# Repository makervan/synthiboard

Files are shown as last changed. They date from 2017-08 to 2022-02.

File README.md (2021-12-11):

# Synthiboard

An Arduino-based synthesizer, with multiple firmwares to allow for different sounds. See http://wiki.makervan.de/wiki/Synthiboard for more information.

## Firmware
There are multiple firmwares available for the Synthiboard, you can find some in this repository.
* Auduino
* R2R Drum Machine
* Glitch Storm by [Spherical Sound Society](https://github.com/spherical-sound-society/glitch-storm), adapted to work with Synthiboard pinout.

## License
Hardware designs created by Severin Schols, and shared under CC-BY-SA-4.0. See LICENSE for more information.

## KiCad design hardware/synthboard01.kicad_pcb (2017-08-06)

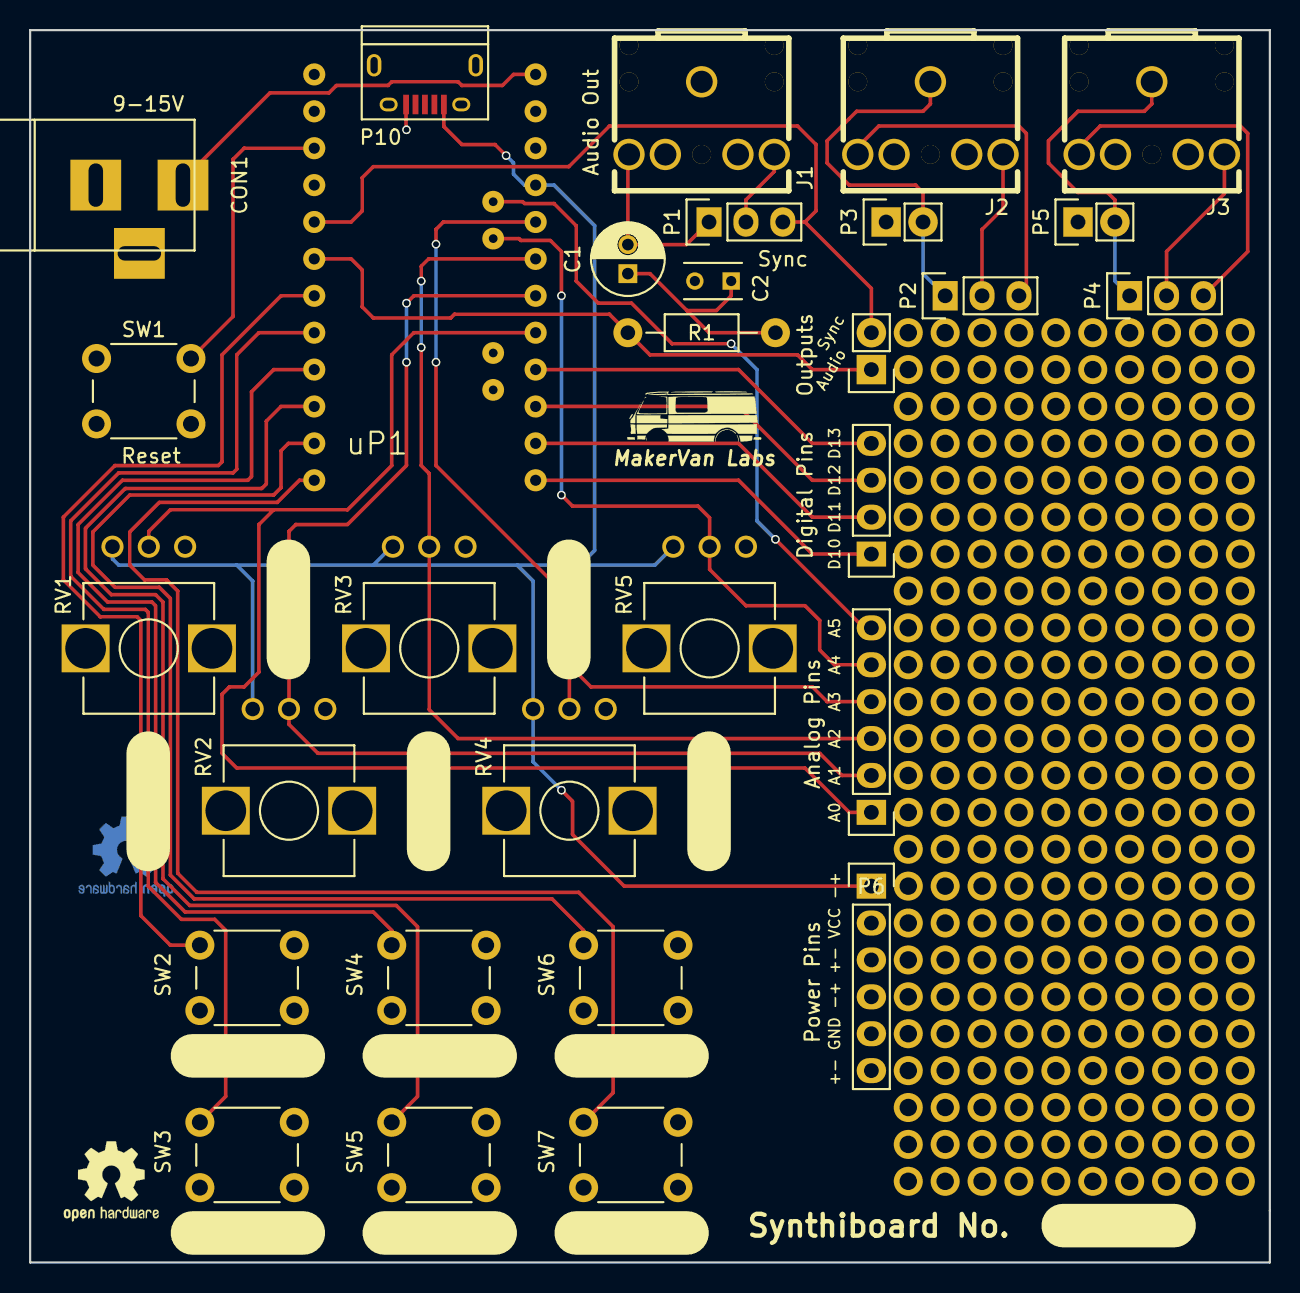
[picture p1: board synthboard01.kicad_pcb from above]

Board: 2 copper layers, 85.3 x 84.8 mm, 30 parts (0 on the bottom side), 31 nets.

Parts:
C1: 10µ; C_Radial_D5_L11_P2
C2: 10n; C_Rect_L4_W2.5_P2.5
CON1: 9-15V; BARREL_JACK
J1: Audio Out; AudioJack3.5mm
J2: Addit. Plug 1; AudioJack3.5mm
J3: Addit. Plug 2; AudioJack3.5mm
P1: Sync; Pin_Header_Straight_1x03
P2: AP1; Pin_Header_Straight_1x03
P3: AP1_GND; Pin_Header_Straight_1x02
P4: AP2; Pin_Header_Straight_1x03
P5: AP2_GND; Pin_Header_Straight_1x02
P6: Analog Pins; Pin_Header_Straight_1x06
P7: Digital Pins; Pin_Header_Straight_1x04
P8: Power Pins; Pin_Header_Straight_1x06
P9: Outputs; Pin_Header_Straight_1x02
P10: USB_OTG; USB_Micro-B
R1: 1k; Resistor_Horizontal_RM10mm
RV1, RV2, RV3, RV4, RV5: 10k; Potentiometer_Alpha-RV09
SW1: Reset; SW_PUSH_6mm
SW2: Button 1; SW_PUSH_6mm
SW3: Button 2; SW_PUSH_6mm
SW4: Button 3; SW_PUSH_6mm
SW5: Button 4; SW_PUSH_6mm
SW6: Button 5; SW_PUSH_6mm
SW7: Button 6; SW_PUSH_6mm
uP1: ARDUPROMINI-6; ArduProMini-6

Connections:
+9V: CON1.1, uP1.19
A0: P6.1, RV1.2, uP1.26
A1: P6.2, RV2.2, uP1.25
A2: P6.3, RV3.2, uP1.24
A3: P6.4, RV4.2, uP1.23
A4: P6.5, RV5.2, uP1.32
A5: P6.6, uP1.31
AudioOut: P9.1, R1.2, uP1.12
D10: P7.1, uP1.30
D11: P7.2, uP1.29
D12: P7.3, uP1.28
D13: P7.4, uP1.27
GND: C2.2, CON1.2, J1.1, P3.1, P5.1, P8.4, P8.5, P8.6, P10.5, RV1.1, RV2.1, RV3.1, RV4.1, RV5.1, SW1.2, SW2.2, SW3.2, SW4.2, SW5.2, SW6.2, SW7.2, uP1.10
unnamed: C1.1, C2.1, R1.1
unnamed: C1.2, J1.2, P1.1
unnamed: J1.3, P1.2
unnamed: J2.1, P2.1, P3.2
unnamed: J2.2, P2.3
unnamed: J2.3, P2.2
unnamed: J3.1, P4.1, P5.2
unnamed: J3.2, P4.3
unnamed: J3.3, P4.2
unnamed: SW1.1, uP1.9
unnamed: SW2.1, uP1.13
unnamed: SW3.1, uP1.14
unnamed: SW4.1, uP1.15
unnamed: SW5.1, uP1.16
unnamed: SW6.1, uP1.17
unnamed: SW7.1, uP1.18
Sync: P1.3, P9.2, uP1.11
VCC: P8.1, P8.2, P8.3, P10.1, RV1.3, RV2.3, RV3.3, RV4.3, RV5.3, uP1.22

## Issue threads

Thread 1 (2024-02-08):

Opening in KiCad 7.

poetaster, 2024-02-08:
Hi! It's not really possible to use the kicad files since a lot of libraries and schematic symbols are missing. Is there any way to update them? Not sure if you have the time, but I'd like to build one!

Thanks!

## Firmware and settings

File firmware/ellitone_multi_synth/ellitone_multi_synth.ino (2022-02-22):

//  ELLITONE MULTI-SYNTH is powered using the Mozzi Sonification Library for Arduino.

// I have spent the last 2.5 years exploring this library, finding the atmega328s strong and weak points when processing realtime audio

// In the following program, I attempted to squeeze as much Mozzi functionality into a single device, paired with a simple "patch and play" interface.

// Currently, this program uses 99.99% of the atmega328 program storage space. This includes the 6 WaveTable files that represent the WaveForm Shapes  <tables/AKWF_.....h>

//You might be asking "can I use my own waveforms?". Creating custom waveforms for use in mozzi is not a simple or straightforward process. Still, you can look more into this process
//by reading through the Mozzi Forum Google Group.

//However, replacing the initial 6 Waveforms with other waveforms from the AKWF library is simple and straightforward! This library contains hundreds of waveshapes that
//can all be viewed here:   https://www.adventurekid.se/AKRTfiles/AKWF/view/waveforms_index.html

//to replace the waveforms, First download and install the Arduino IDE:  https://www.arduino.cc/en/Main/Software

//Next, download and unzip the Mozzi file. Take the unzipped Mozzi folder and place it inside the "libraries" folder located within the Arduino Folder, (usually found in My Documents).

//Now, make sure you have successfully installed the CH340 Driver. This driver allows your computer to communicate with the Ellitones atmega328.
//If installed correctly, your computer should recognize the Arduino when plugged into USB and it will show up as a COM in Tools-Port menu in Arduino IDE

//Now, Navigate to Documents > Arduino > libraries > Mozzi-1.0.3rc6 > tables
//Scroll down until you start seeing the files that start with "AKWF" these are all the possible waveforms you can choose from!

//Next, in the #include section below, copy in the waveshape files you want to use instead of the 6 that are currently there.

//Next, Around Code Line ~93 (current line code # is in bottom left hand corner of Arduino IDE window) make sure that one of your new wavetables is used here instead of old waveform!
//Code Line ~246, make sure that one of your new wavetables is used here aswell!

//Lastly, Code Line ~869 through ~946 is where the actual switching between waveforms happen when you connect different outputs to the WaveForm input.
//This is where you will put in all your new selected waveform files!

//If you wish to try adding new features and modes, one way to quickly free up a bunch of space (to work with) is to #include and use LESS than 6 WaveForms.
//You can just use 1 waveform file in all the places listed above and free up ~40% more space for added logic functions!

//I am more than happy to further explain the following code and its workings if people are interested in taking this device even further!
//Feel free to email me at ellistronics.usa@gmail.com



#include <MozziGuts.h>        //loads all the essential mozzi engine stuff 
#include <Oscil.h>           //loads behind the scenes oscillator magic
#include <EventDelay.h>   //used throughout this program as "timers" in place of the usual arduino "delay" functions which are disabled by mozzi workings
#include <Ead.h>              // stands for Exponential Attack Decay (Envelope). This loads the behind the scenes envelope magic
#include <WavePacket.h>          //loads "chirp" type synthesis engine 
#include <Smooth.h>          //loads basic smoothing filter (not for audio). used to smooth the jumpy analog data readings from the 4 knobs 

#include <tables/cos2048_int8.h>      // loads cosine wavetable used in the FM mode (FreqModz)

#include "tables/AKWF_oscchip_0100_512.h"    //loads the 6 wavetables for use in modes: 1(wavetables),2(patterns),5(infinite bounce),6(panic voice)
#include "tables/AKWF_vgsaw_0005_512.h"
#include "tables/AKWF_nes_square_512.h"
#include "tables/AKWF_hvoice_0010_512.h"
#include "tables/AKWF_hvoice_0020_512.h"
#include "tables/AKWF_vgame_0126_512.h"


// INPUT PINS
#define POT1_PIN A0
#define POT2_PIN A1
#define POT3_PIN A2
#define POT4_PIN A3

#define BUTTON1_PIN 4
#define BUTTON2_PIN 5
#define BUTTON3_PIN 6
#define BUTTON4_PIN 7

#define OPT_WAVEFORM_PIN  A4
#define OPT_VOICING_PIN   A5
#define OPT_PLAYSTYLE_PIN 10
#define OPT_SPEED_PIN     11
#define OPT_RHYTHM_PIN    12

// OUTPUT PINS
#define OPT_OUT1_PIN 0
#define OPT_OUT2_PIN 1
#define OPT_OUT3_PIN 2
#define OPT_OUT4_PIN 3
#define OPT_OUT5_PIN 8
#define OPT_OUT6_PIN 13

EventDelay pulse1, pulse2, pulse3, pulse4, pulse5, pulse6; //option outpus 1-6

EventDelay offTimer1, offTimer2, offTimer3, offTimer4, offTimer5;              //this stuff will be explained further on down. Just initializing variables here
byte counter1, counter2, counter3, counter4, counter5, counter6 = 1;

int pulseCounter1 = 1;
int pulseCounter2 = 1;
int pulseCounter3 = 1;
int pulseCounter4 = 1;
int pulseCounter5 = 1;

bool reset1 = true;
byte outPut1;

bool reset2 = true;
byte outPut2;

bool reset3 = true;
byte outPut3;

bool reset4 = true;
byte outPut4;

bool reset5 = true;
byte outPut5;

bool reset6 = true;
byte outPut6;


Oscil <AKWF_oscchip_0100_512_NUM_CELLS, AUDIO_RATE> aSin1;     //initializes the wavetable type oscillators
Oscil <AKWF_oscchip_0100_512_NUM_CELLS, AUDIO_RATE> aSin2;
Oscil <AKWF_oscchip_0100_512_NUM_CELLS, AUDIO_RATE> aSin3;    //if you are using different waveforms, you must use one of your new waveform files here instead of this old one.
Oscil <AKWF_oscchip_0100_512_NUM_CELLS, AUDIO_RATE> aSin4;
Oscil <AKWF_oscchip_0100_512_NUM_CELLS, AUDIO_RATE> aSin5;
Oscil <AKWF_oscchip_0100_512_NUM_CELLS, AUDIO_RATE> aSin6;
Oscil <AKWF_oscchip_0100_512_NUM_CELLS, AUDIO_RATE> aSin7;
Oscil <AKWF_oscchip_0100_512_NUM_CELLS, AUDIO_RATE> aSin8;


Oscil<COS2048_NUM_CELLS, AUDIO_RATE> aCarrier(COS2048_DATA);    //initialzies the FM mode oscillators
Oscil<COS2048_NUM_CELLS, AUDIO_RATE> aModulator(COS2048_DATA);
Oscil<COS2048_NUM_CELLS, CONTROL_RATE> kModIndex(COS2048_DATA);



byte gain1, gain2, gain3, gain4, gain5, gain6, gain7, gain8 = 1;

byte envGain1, envGain2, envGain3, envGain4, envGain5, envGain6, envGain7, envGain8 = 255; //just initializing more stuff for later on

byte key = 1;     //the most current key button that was last pressed (1-4)
byte mode = 1;

int p1 = 100;    //4 pitches
int p2 = 100;
int p3 = 100;
int p4 = 100;

int pitchAlter = 0; //used for sequence transposing

EventDelay seqTimer;
byte seqPos = 1;

Ead envelope1(CONTROL_RATE), envelope2(CONTROL_RATE), envelope3(CONTROL_RATE), envelope4(CONTROL_RATE); //initializes envelopes with the same resolution as our run time (CONTROL_RATE)

int tempGain;

EventDelay speedsTimer;    //speeds

EventDelay newRandrh;
EventDelay newRandvoicing;

int step1rh = 200;          //seriously, dont worry about all these weird variables till later.
int step2rh = 200;
int step3rh = 200;
int step4rh = 200;


byte stepNum = 1;

int attack = 100; //envelope stuff
int decay = 100;

int fmLevel;

int fmGain;

WavePacket <DOUBLE> wavey;       //initializes "chirp" sound engine (referred to as a WavePacket in Mozzi terms)

float keySpread;
float waveyFund;


EventDelay bounceTimer1, bounceTimer2, bounceTimer3, bounceTimer4; //timers used in the infinite bounce matter mode to trigger the envelopes

EventDelay randomPulse;



int bounceTime1, bounceTime2, bounceTime3, bounceTime4 = 10; //actual bounce times for infinite bounce mode



float enhance;       //panic voice engine variables being simply initialized here
float finalFreq;
float alter;
int freq = 500;

byte modGain = 255;

int pulse6Time;
byte rando;

int speeds;

byte rhtime1 = 1;
byte rhtime2 = 1;
byte rhtime3 = 1;
byte rhtime4 = 1;

byte voicing1 = 1;    //these are the chord divisions for the voicing control
byte voicing2 = 1;
byte voicing3 = 1;
byte voicing4 = 1;

int randoPulseTime;


int modFreq = 100;

Smooth <int> smoothKnob1(0.92f);     //sets up smoothing filters that we will run our raw potentiometer (knob) readings through to get steady pitch settings
Smooth <int> smoothKnob2(0.92f);
Smooth <int> smoothKnob3(0.92f);
Smooth <int> smoothKnob4(0.92f);

int baseSpeed;
int speed1;
int speed2;
int speed3;
int speed4;
int speed5;

float sin2Freq;

int rawA7 = 100;       //raw potentiometer (knob) readings
int rawA6 = 100;
int rawA0 = 100;
int rawA1 = 100;

int phold1 = 100;
int phold2 = 100;
int phold3 = 100;
int phold4 = 100;


int freakFreq = 0;
int waveyFreak = 0;

int riggy;

#define CONTROL_RATE 64       //this entire mozzi engine program operates at a click rate determined here. this is how fast the programs updateControl() section will loop 




void setup() {

  startMozzi(CONTROL_RATE);   //starts the entire mozzi engine at the control rate

  randomSeed(mozziAnalogRead(POT1_PIN));     //takes a quick reading of potentiometer (knob) A7 and bases its psuedo random # generator on it to calculate the following random values

  baseSpeed = random(200, 400);
  speed1 = random(50, 100);
  speed2 = random(100, 250);
  speed3 = random(300, 500);
  speed4 = random(500, 1000);
  speed5 = random(500, 2000);

  randoPulseTime = random(200, 800);

  riggy = random(10, 1000);


  aSin1.setTable(AKWF_vgsaw_0005_512_DATA);   //not too important. still just setting up the oscillators with initial wavetable shape data
  aSin2.setTable(AKWF_vgsaw_0005_512_DATA);
  aSin3.setTable(AKWF_vgsaw_0005_512_DATA);
  aSin4.setTable(AKWF_vgsaw_0005_512_DATA);    //if you are using different waveform files, you MUST use one of your new waveform files here instead.
  aSin5.setTable(AKWF_vgsaw_0005_512_DATA);
  aSin6.setTable(AKWF_vgsaw_0005_512_DATA);
  aSin7.setTable(AKWF_vgsaw_0005_512_DATA);
  aSin8.setTable(AKWF_vgsaw_0005_512_DATA);


  // Serial.begin(9600);   //for debugging


  pinMode(BUTTON1_PIN, INPUT_PULLUP); //button 1     //4 key buttons are "pulled-up" to HIGH +5V signal. When pressed, they connect the input pin to GROUND which will now
  pinMode(BUTTON2_PIN, INPUT_PULLUP); //button 2      read as LOW in the code. this may seem confusing at first but HIGH means that button IS NOT pressed and
  pinMode(BUTTON3_PIN, INPUT_PULLUP);  //button 3      LOW means that the button IS pressed
  pinMode(BUTTON4_PIN, INPUT_PULLUP); //button 4


  pinMode(OPT_WAVEFORM_PIN, INPUT_PULLUP);   //waveform        //
  pinMode(OPT_VOICING_PIN, INPUT_PULLUP);   //voicing
  pinMode(OPT_PLAYSTYLE_PIN, INPUT_PULLUP);   //play style
  pinMode(OPT_SPEED_PIN, INPUT_PULLUP);   //speed
  pinMode(OPT_RHYTHM_PIN, INPUT_PULLUP);   //rhythm



  pinMode(OPT_OUT6_PIN, OUTPUT);   //6
  pinMode(OPT_OUT5_PIN, OUTPUT);   //5       //Option Outputs 1-6
  pinMode(OPT_OUT4_PIN, OUTPUT);   //4
  pinMode(OPT_OUT3_PIN, OUTPUT);   //3
  pinMode(OPT_OUT2_PIN, OUTPUT);   //2
  pinMode(OPT_OUT1_PIN, OUTPUT);    //1

  pulse1.start(100);        //This sections simply "starts" all the little timers that will be used throughout the program
  pulse2.start(100);
  pulse3.start(100);
  pulse4.start(100);
  pulse5.start(100);

  seqTimer.start(100);
  speedsTimer.start(100);

  bounceTimer1.start(100);
  bounceTimer2.start(100);
  bounceTimer3.start(100);
  bounceTimer4.start(100);

  randomPulse.start(200);

  newRandrh.start(5000);
  newRandvoicing.start(500);

}


void updateControl() {


  phold1 = smoothKnob1.next(mozziAnalogRead(POT1_PIN));  // from right to left:  takes raw analog knob reading (mozziAnalogRead()) ,smooths them (smoothKnob), then sets
  phold2 = smoothKnob2.next(mozziAnalogRead(POT2_PIN));  // phold variable (final pitch) with the final smoothed output
  phold3 = smoothKnob3.next(mozziAnalogRead(POT3_PIN));
  phold4 = smoothKnob4.next(mozziAnalogRead(POT4_PIN));


  if (phold1 > rawA7 + 2 || phold1 < rawA7 - 2) {      // this section here performs a "pitch hold" where the new incoming pitch values must be either +3 or -3 compared
    rawA7 = phold1;                                      //   to the held value in order to update the final pitch
  }
  if (phold2 > rawA6 + 2 || phold2 < rawA6 - 2) {
    rawA6 = phold2;
  }
  if (phold3 > rawA0 + 2 || phold3 < rawA0 - 2) {
    rawA0 = phold3;
  }
  if (phold4 > rawA1 + 2 || phold4 < rawA1 - 2) {
    rawA1 = phold4;
  }





  if (mode == 6) {                             /////////////////////////////PANIC VOICE (mode 6) WORKINGS

    if (outPut1 == 0 && outPut2 == 0) {

      if (outPut4 != 0) {
        freakFreq = riggy * outPut4;
      }
      if (outPut5 != 0) {
        freakFreq = riggy / outPut5;
      }
    } else {
      freakFreq = 0;
    }


    enhance = map(rawA6, 0, 1023, 10, 255); //Push/Strength Control here was called "enhance" during dev.
    enhance = enhance * 0.007;

    if (outPut1 == 0) {
      modGain = map(rawA1, 0, 1023, 0, 255);
    } else {
      if (envelope1.next() != 0) {
        modGain = (envelope1.next() * rawA1);
      } else {
        modGain = map(rawA1, 0, 1023, 0, 255);
      }
    }

    if (outPut2 == 0) {
      sin2Freq = p3 * 10;
    } else {
      if (envelope1.next() != 0) {
        sin2Freq = (envelope1.next() * (rawA0 >> 4));
      } else {
        sin2Freq = p3 * 10;
      }
    }


    alter = map(rawA7, 0, 1023, 400, 200);

    finalFreq = freq * alter;

    aSin2.setFreq(sin2Freq + freakFreq);
    aSin1.setFreq(finalFreq);

  }

  ///////////////////////////////////////////////////////////////////////////////////////////////////////////// WAVETABLE (mode 1) WORKINGS


  if (digitalRead(BUTTON1_PIN) == LOW) {
    key = 1;
    freq = 100;
  }
  if (digitalRead(BUTTON2_PIN) == LOW) {
    key = 2;
    freq = 500;
  }
  if (digitalRead(BUTTON3_PIN) == LOW) {
    key = 3;
    freq = 900;
  }
  if (digitalRead(BUTTON4_PIN) == LOW) {
    key = 4;
    freq = 1500;
  }


  p1 = rawA7;
  p2 = rawA6;
  p3 = rawA0;
  p4 = rawA1;





  /////////////////////////////////////////////////////////////////////////////////////////////////  "CHIRP" (mode 4) - WAVEPACKET WORKINGS

  if (mode == 4) {


    if (outPut1 == 0 && outPut2 == 0) { //basically, if there is no attachment but a speed or rhythm is in fact selected then

      if (outPut4 != 0) {
        waveyFreak = outPut4 * 250;
      }
      if (outPut5 != 0) {
        waveyFreak = outPut5 * 250;
      }
    } else {
      waveyFreak = 0;
    }



    if (outPut1 == 0) {                                     //if waveform is 0 then set by knob. otherwise, set bandwidth control by envelope
      wavey.setBandwidth((rawA7 * 2) + waveyFreak);
    } else {
      wavey.setBandwidth((envelope1.next() * (rawA7 >> 5)) + (outPut1 * 100));
    }

    if (outPut2 == 0) {
      wavey.setCentreFreq((rawA6 * 2) + waveyFreak);               //if voicing is 0 then set by knob. otherwise, set centrefreq by envelope
    } else {
      wavey.setCentreFreq((envelope1.next() * (rawA6 >> 5)) + (outPut2 * 200));
    }

    waveyFund = rawA0 >> 4;

    keySpread = rawA1 / 1023.0; //converts 10-bit analog reading (0-1023) to float range between (0.00-1.00)


    float finekey = keySpread * waveyFund;


    if (key == 1) {
      wavey.setFundamental(waveyFund + (finekey * 0.50)); //Sets coarse frequency based on the "base frequency" control plus the "key note spread" control times 0.5,1.0,1.5,2.0
    }
    if (key == 2) {
      wavey.setFundamental(waveyFund + (finekey * 1.0));
    }
    if (key == 3) {
      wavey.setFundamental(waveyFund + (finekey * 1.5));
    }
    if (key == 4) {
      wavey.setFundamental(waveyFund + (finekey * 2.0));
    }

  }





  ///////////////////////////////////////////////////////////////////////////////////////FM (mode 3) WORKINGS



  if (mode == 3 && outPut4 == 0 && outPut5 == 0) { //if mode is fm and speed is 0 (base) and rhthym is 0 (base), then set main pitches by 4 Keys

    if (key == 1) {
      aCarrier.setFreq(p1);
    }
    if (key == 2) {
      aCarrier.setFreq(p2);
    }
    if (key == 3) {
      aCarrier.setFreq(p3);
    }
    if (key == 4) {
      aCarrier.setFreq(p4);
    }

  }







  ///////////////////////// RANDOM VOICING RATIO CREATOR

  if (outPut2 != 0) {
    newRandvoicing.start(300);
  }

  if (newRandvoicing.ready()) {

    voicing1 = random(1, 8);
    voicing2 = random(1, 8);
    voicing3 = random(1, 8);
    voicing4 = random(1, 8);

    newRandvoicing.start();
  }





  if (mode == 1) {                                      //////WAVETABLE (mode 1)


    if (key == 1) {
      aSin1.setFreq(p1);
      aSin2.setFreq(p1 + (p1 / voicing1));
      aSin3.setFreq(p1 + (p1 / voicing2));
      aSin4.setFreq(p1 + (p1 / voicing3));
      aSin5.setFreq(p1 + (p1 / voicing4));
      aSin6.setFreq((p1 * 2) + (p1 / voicing1));
      aSin7.setFreq((p1 * 2) + (p1 / voicing2));
      aSin8.setFreq((p1 * 2) + (p1 / voicing3));
    }
    if (key == 2) {
      aSin1.setFreq(p2);
      aSin2.setFreq(p2 + (p2 / voicing1));
      aSin3.setFreq(p2 + (p2 / voicing2));
      aSin4.setFreq(p2 + (p2 / voicing3));
      aSin5.setFreq(p2 + (p2 / voicing4));
      aSin6.setFreq((p2 * 2) + (p2 / voicing1));
      aSin7.setFreq((p2 * 2) + (p2 / voicing2));
      aSin8.setFreq((p2 * 2) + (p2 / voicing3));
    }
    if (key == 3) {
      aSin1.setFreq(p3);
      aSin2.setFreq(p3 + (p3 / voicing1));
      aSin3.setFreq(p3 + (p3 / voicing2));
      aSin4.setFreq(p3 + (p3 / voicing3));
      aSin5.setFreq(p3 + (p3 / voicing4));
      aSin6.setFreq((p3 * 2) + (p3 / voicing1));
      aSin7.setFreq((p3 * 2) + (p3 / voicing2));
      aSin8.setFreq((p3 * 2) + (p3 / voicing3));
    }
    if (key == 4) {
      aSin1.setFreq(p4);
      aSin2.setFreq(p4 + (p4 / voicing1));
      aSin3.setFreq(p4 + (p4 / voicing2));
      aSin4.setFreq(p4 + (p4 / voicing3));
      aSin5.setFreq(p4 + (p4 / voicing4));
      aSin6.setFreq((p4 * 2) + (p4 / voicing1));
      aSin7.setFreq((p4 * 2) + (p4 / voicing2));
      aSin8.setFreq((p4 * 2) + (p4 / voicing3));
    }

    tempGain = (int) envelope1.next();
    envGain1 = tempGain;
    envGain2 = tempGain;
    envGain3 = tempGain;
    envGain4 = tempGain;
    envGain5 = tempGain;
    envGain6 = tempGain;
    envGain7 = tempGain;
    envGain8 = tempGain;

  }

  //////////////////////////////////////////////////////////////////INFINITE BOUNCE MATTER (mode5)


  if (mode == 5) {

    if (bounceTimer1.ready()) {           //if timer has reached the end,
      envelope1.start(attack, decay);         //do action
      bounceTimer1.start(bounceTime1);       //then reset the timer
    }

    if (bounceTimer2.ready()) {
      envelope2.start(attack, decay);
      bounceTimer2.start(bounceTime2);
    }

    if (bounceTimer3.ready()) {
      envelope3.start(attack, decay);
      bounceTimer3.start(bounceTime3);
    }

    if (bounceTimer4.ready()) {
      envelope4.start(attack, decay);
      bounceTimer4.start(bounceTime4);
    }


    envGain1 = (int) envelope1.next();      //translates envelope data into gain data for individual voice volumes
    envGain2 = (int) envelope2.next();
    envGain3 = (int) envelope3.next();
    envGain4 = (int) envelope4.next();




    if (outPut2 == 0) {
      aSin1.setFreq(p1);
      aSin2.setFreq(p2);
      aSin3.setFreq(p3);
      aSin4.setFreq(p4);
      gain1 = 1;
      gain2 = 1;
      gain3 = 1;
      gain4 = 1;
      gain5 = 0;
      gain6 = 0;
      gain7 = 0;
      gain8 = 0;
    }




    if (outPut2 == 2) {
      aSin1.setFreq(p1);
      aSin2.setFreq(p2);
      aSin3.setFreq(p3);
      aSin4.setFreq(p4);
      aSin5.setFreq(p1 + 2);
      aSin6.setFreq(p2 - 2);
      aSin7.setFreq(p3 + 2);
      aSin8.setFreq(p4 - 2);
    }

    if (outPut2 == 3) {
      aSin1.setFreq(p1);
      aSin2.setFreq(p2);
      aSin3.setFreq(p3);
      aSin4.setFreq(p4);
      aSin5.setFreq((p1 * 2) + 2);
      aSin6.setFreq((p2 * 2) - 2);
      aSin7.setFreq((p3 * 2) + 2);
      aSin8.setFreq((p4 * 2) - 2);
    }

    if (outPut2 == 5) {
      aSin1.setFreq(p1);
      aSin2.setFreq(p2);
      aSin3.setFreq(p3);
      aSin4.setFreq(p4);
      aSin5.setFreq(p1 * voicing1);
      aSin6.setFreq(p2 * voicing1);
      aSin7.setFreq(p3 * voicing1);
      aSin8.setFreq(p4 * voicing1);
    }

    if (outPut2 == 6) {
      aSin1.setFreq(p1);
      aSin2.setFreq(p2);
      aSin3.setFreq(p3);
      aSin4.setFreq(p4);
      aSin5.setFreq(p1 * voicing2);
      aSin6.setFreq(p2 * voicing2);
      aSin7.setFreq(p3 * voicing2);
      aSin8.setFreq(p4 * voicing2);
    }

    if (outPut2 == 7) {
      aSin1.setFreq(p1);
      aSin2.setFreq(p2);
      aSin3.setFreq(p3);
      aSin4.setFreq(p4);
      aSin5.setFreq(p1 * voicing1);
      aSin6.setFreq(p2 * voicing2);
      aSin7.setFreq(p3 * voicing3);
      aSin8.setFreq(p4 * voicing4);
    }

    if (outPut2 != 0) {                                              //if voicing is zero than all gains are on / gains 1-8 are either 1 (on) or 0 (off)
      gain1 = 1;
      gain2 = 1;
      gain3 = 1;
      gain4 = 1;
      gain5 = 1;
      gain6 = 1;
      gain7 = 1;
      gain8 = 1;
    }



    if (digitalRead(BUTTON1_PIN) == LOW) {        ///INCREASE BOUNCE TIMES WITH KEYS
      bounceTime1 = bounceTime1 + 3;
    }
    if (digitalRead(BUTTON2_PIN) == LOW) {
      bounceTime2 = bounceTime2 + 3;
    }
    if (digitalRead(BUTTON3_PIN) == LOW) {
      bounceTime3 = bounceTime3 + 3;
    }
    if (digitalRead(BUTTON4_PIN) == LOW) {
      bounceTime4 = bounceTime4 + 3;
    }

  }

  if (mode != 5) {             //once mode is changed, all bounce times reset to 100 millis
    bounceTime1 = 100;
    bounceTime2 = 100;
    bounceTime3 = 100;
    bounceTime4 = 100;
  }

  ////////////////////////////////////////////////////////////////////////////////////////////////////////////END OF BOUNCE MODE






  ////////////////////////////////////////////////  CENTER PATCH BAY AREA WORKINGS
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
void loop() {
  audioHook();    //actual loop section which crunches all the audio date in updateAudio() above
}

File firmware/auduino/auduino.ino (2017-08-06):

// Auduino, the Lo-Fi granular synthesiser
//
// by Peter Knight, Tinker.it http://tinker.it
//
// Help:      http://code.google.com/p/tinkerit/wiki/Auduino
// More help: http://groups.google.com/group/auduino
//
// Analog in 0: Grain 1 pitch
// Analog in 1: Grain 2 decay
// Analog in 2: Grain 1 decay
// Analog in 3: Grain 2 pitch
// Analog in 4: Grain repetition frequency
//
// Digital 3: Audio out (Digital 11 on ATmega8)
//
// Changelog:
// 19 Nov 2008: Added support for ATmega8 boards
// 21 Mar 2009: Added support for ATmega328 boards
// 7 Apr 2009: Fixed interrupt vector for ATmega328 boards
// 8 Apr 2009: Added support for ATmega1280 boards (Arduino Mega)

#include <avr/io.h>
#include <avr/interrupt.h>

uint16_t syncPhaseAcc;
uint16_t syncPhaseInc;
uint16_t grainPhaseAcc;
uint16_t grainPhaseInc;
uint16_t grainAmp;
uint8_t grainDecay;
uint16_t grain2PhaseAcc;
uint16_t grain2PhaseInc;
uint16_t grain2Amp;
uint8_t grain2Decay;

// Map Analogue channels
#define SYNC_CONTROL         (4)
#define GRAIN_FREQ_CONTROL   (0)
#define GRAIN_DECAY_CONTROL  (2)
#define GRAIN2_FREQ_CONTROL  (3)
#define GRAIN2_DECAY_CONTROL (1)


// Changing these will also requires rewriting audioOn()

#if defined(__AVR_ATmega8__)
//
// On old ATmega8 boards.
//    Output is on pin 11
//
#define LED_PIN       13
#define LED_PORT      PORTB
#define LED_BIT       5
#define PWM_PIN       11
#define PWM_VALUE     OCR2
#define PWM_INTERRUPT TIMER2_OVF_vect
#elif defined(__AVR_ATmega1280__)
//
// On the Arduino Mega
//    Output is on pin 3
//
#define LED_PIN       13
#define LED_PORT      PORTB
#define LED_BIT       7
#define PWM_PIN       3
#define PWM_VALUE     OCR3C
#define PWM_INTERRUPT TIMER3_OVF_vect
#else
//
// For modern ATmega168 and ATmega328 boards
//    Output is on pin 3
//
#define PWM_PIN       3
#define PWM_VALUE     OCR2B
#define LED_PIN       13
#define LED_PORT      PORTB
#define LED_BIT       5
#define PWM_INTERRUPT TIMER2_OVF_vect
#define MODE_PIN_1    8
#define MODE_PIN_2    9
#endif

// Smooth logarithmic mapping
//
uint16_t antilogTable[] = {
  64830,64132,63441,62757,62081,61413,60751,60097,59449,58809,58176,57549,56929,56316,55709,55109,
  54515,53928,53347,52773,52204,51642,51085,50535,49991,49452,48920,48393,47871,47356,46846,46341,
  45842,45348,44859,44376,43898,43425,42958,42495,42037,41584,41136,40693,40255,39821,39392,38968,
  38548,38133,37722,37316,36914,36516,36123,35734,35349,34968,34591,34219,33850,33486,33125,32768
};
uint16_t mapPhaseInc(uint16_t input) {
  return (antilogTable[(1023 - input) & 0x3f]) >> ((1023 - input) >> 6);
}

// Stepped chromatic mapping
//
uint16_t midiTable[] = {
  17,18,19,20,22,23,24,26,27,29,31,32,34,36,38,41,43,46,48,51,54,58,61,65,69,73,
  77,82,86,92,97,103,109,115,122,129,137,145,154,163,173,183,194,206,218,231,
  244,259,274,291,308,326,346,366,388,411,435,461,489,518,549,581,616,652,691,
  732,776,822,871,923,978,1036,1097,1163,1232,1305,1383,1465,1552,1644,1742,
  1845,1955,2071,2195,2325,2463,2610,2765,2930,3104,3288,3484,3691,3910,4143,
  4389,4650,4927,5220,5530,5859,6207,6577,6968,7382,7821,8286,8779,9301,9854,
  10440,11060,11718,12415,13153,13935,14764,15642,16572,17557,18601,19708,20879,
  22121,23436,24830,26306
};
uint16_t mapMidi(uint16_t input) {
  return (midiTable[(input) >> 3]);
}

// Stepped Pentatonic mapping
//
uint16_t pentatonicTable[54] = {
  0,19,22,26,29,32,38,43,51,58,65,77,86,103,115,129,154,173,206,231,259,308,346,
  411,461,518,616,691,822,923,1036,1232,1383,1644,1845,2071,2463,2765,3288,
  3691,4143,4927,5530,6577,7382,8286,9854,11060,13153,14764,16572,19708,22121,26306
};

uint16_t mapPentatonic(uint16_t input) {
  uint8_t value = (input) / (1024/53);
  return (pentatonicTable[value]);
}


void audioOn() {
#if defined(__AVR_ATmega8__)
  // ATmega8 has different registers
  TCCR2 = _BV(WGM20) | _BV(COM21) | _BV(CS20);
  TIMSK = _BV(TOIE2);
#elif defined(__AVR_ATmega1280__)
  TCCR3A = _BV(COM3C1) | _BV(WGM30);
  TCCR3B = _BV(CS30);
  TIMSK3 = _BV(TOIE3);
#else
  // Set up PWM to 31.25kHz, phase accurate
  TCCR2A = _BV(COM2B1) | _BV(WGM20);
  TCCR2B = _BV(CS20);
  TIMSK2 = _BV(TOIE2);
#endif
}


void setup() {
  pinMode(PWM_PIN,OUTPUT);
  audioOn();
  pinMode(LED_PIN,OUTPUT);
  
  pinMode(MODE_PIN_1, INPUT);
  digitalWrite(MODE_PIN_1, HIGH);
  pinMode(MODE_PIN_2, INPUT);
  digitalWrite(MODE_PIN_2, HIGH);
}

void loop() {
  // The loop is pretty simple - it just updates the parameters for the oscillators.
  //
  // Avoid using any functions that make extensive use of interrupts, or turn interrupts off.
  // They will cause clicks and poops in the audio.
 
  //if (digitalRead(MODE_PIN_1) == LOW) {
    // Smooth frequency mapping
//    syncPhaseInc = mapPhaseInc(analogRead(SYNC_CONTROL)) / 4;
//  } else if (digitalRead(MODE_PIN_2) == LOW) {
    // Stepped mapping to MIDI notes: C, Db, D, Eb, E, F...
    syncPhaseInc = mapMidi(analogRead(SYNC_CONTROL));
//  } else {
    // Stepped pentatonic mapping: D, E, G, A, B
//    syncPhaseInc = mapPentatonic(analogRead(SYNC_CONTROL));
//  }
  
  grainPhaseInc  = mapPhaseInc(analogRead(GRAIN_FREQ_CONTROL)) / 2;
  grainDecay     = analogRead(GRAIN_DECAY_CONTROL) / 8;
  grain2PhaseInc = mapPhaseInc(analogRead(GRAIN2_FREQ_CONTROL)) / 2;
  grain2Decay    = analogRead(GRAIN2_DECAY_CONTROL) / 4;
}

SIGNAL(PWM_INTERRUPT)
{
  uint8_t value;
  uint16_t output;

  syncPhaseAcc += syncPhaseInc;
  if (syncPhaseAcc < syncPhaseInc) {
    // Time to start the next grain
    grainPhaseAcc = 0;
    grainAmp = 0x7fff;
    grain2PhaseAcc = 0;
    grain2Amp = 0x7fff;
    LED_PORT ^= 1 << LED_BIT; // Faster than using digitalWrite
  }
 
  // Increment the phase of the grain oscillators
  grainPhaseAcc += grainPhaseInc;
  grain2PhaseAcc += grain2PhaseInc;

  // Convert phase into a triangle wave
  value = (grainPhaseAcc >> 7) & 0xff;
  if (grainPhaseAcc & 0x8000) value = ~value;
  // Multiply by current grain amplitude to get sample
  output = value * (grainAmp >> 8);

  // Repeat for second grain
  value = (grain2PhaseAcc >> 7) & 0xff;
  if (grain2PhaseAcc & 0x8000) value = ~value;
  output += value * (grain2Amp >> 8);

  // Make the grain amplitudes decay by a factor every sample (exponential decay)
  grainAmp -= (grainAmp >> 8) * grainDecay;
  grain2Amp -= (grain2Amp >> 8) * grain2Decay;

  // Scale output to the available range, clipping if necessary
  output >>= 9;
  if (output > 255) output = 255;

  // Output to PWM (this is faster than using analogWrite)  
  PWM_VALUE = output;
}

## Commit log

2021-12-11 Add glitch storm code
    [ecuaciones.ino, glitch_storm.ino]
2021-12-11 Fix regular R2R Drum Machine
    [r2r_drum_machine_pwm.ino]
2026-03-22 migrate v0.1 to kicad 9

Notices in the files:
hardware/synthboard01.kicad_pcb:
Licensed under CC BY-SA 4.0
